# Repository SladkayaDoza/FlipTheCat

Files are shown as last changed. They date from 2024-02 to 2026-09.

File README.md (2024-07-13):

# FlipTheCat

Multitool for working with radio signals, based on FlipperZero on the basis of esp32 with less functionality and completely self-assembly. Use cc1101 module.
___
I really want to write programs in flipper zero, but I don't have the money for it.  
I would appreciate any support.
Metamask - 0x55aB63c8359f82a16f5B1eb500CaBc8DB605ACE0

## Functions
- copying of an unlimited number of static signals (can be set in firmware)
- change signal code, rename signal name, delete code
- copy raw signal (start recording when signal appears on air), display signal data quantity, rename signal, delete signal
- On-air frequency analyzer, sensitivity setting, frequency tabular value output, received signal frequency output
- Brute force of 12 bit signals for opening of cinder barriers
- Bluetooth BLE emulation Keyboard (gamepad)
- GPIO Frequency generator, set frequency and filling
- Setting the broadcasting frequency and the start num of the 12-bit signal brute force
- Game 2048

## ToDo
- https://trello.com/b/FfUWApZh/flip-esp32

## Open Project
You can suggest changes or additional features

## Materials:
- cc1101 module
- lithium battery
- esp32 (s, s3, an other.., flash: 4+mb)
- 10 smd buttons (2 for up gamepad buttons)
- tp4057 type c charger with protection
- step up dc-dc and linear voltage stabilizer | or step up, down corverter 3.3v
- gpio output pins x18 (4+10+4)
- power switch
- 8 resistors 10k(5 for buttons, 2 for boot pins esp32, 1 for buzzer transistor), 3 resistors 100k (1 for buttons, 2 for volltage censor), 1 resistor 600 Ohm (for led)
- oled display 1.3"
- yellow led for indicator
- 2 capacitor (10v 220uf, 10v, 220pf)
- Buzzer 3.3v
- Transistor for buzzer

## After assembling
Once created, you need to calibrate the buttons and the resistive divider to output the battery voltage
* To calibrate the buttons, uncomment line 11 in the "tick.ino" file
* To calibrate the voltage you need to change the coefficients in the Function mainn()
According to the formula - getVolltage() * 3.26 * ((r1 + r2) / r2) / 4096
When connecting to a computer via UART, do not connect 3.3v from the programmer, for correct display of values from the buttons

## © Copyright
* ✖ | Not Commercial Use

##	Example of a finished product:
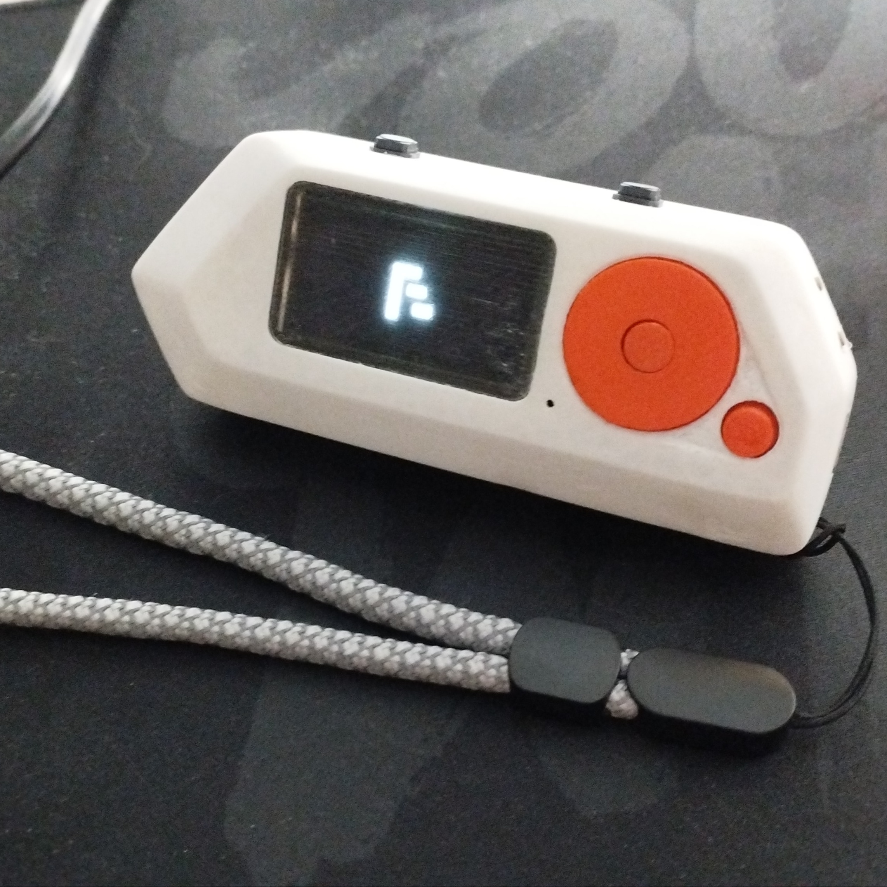
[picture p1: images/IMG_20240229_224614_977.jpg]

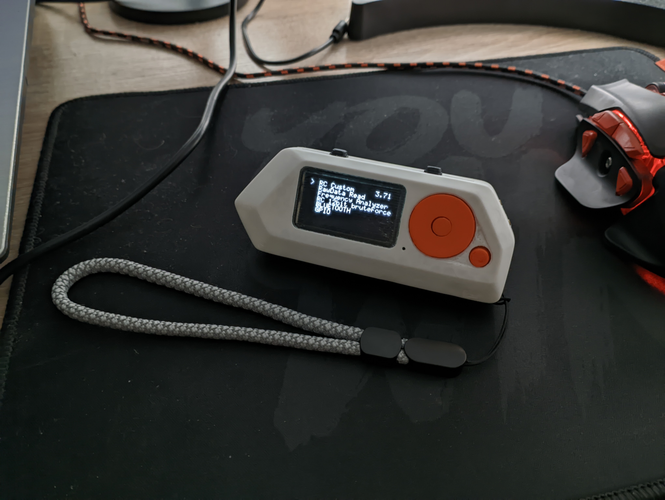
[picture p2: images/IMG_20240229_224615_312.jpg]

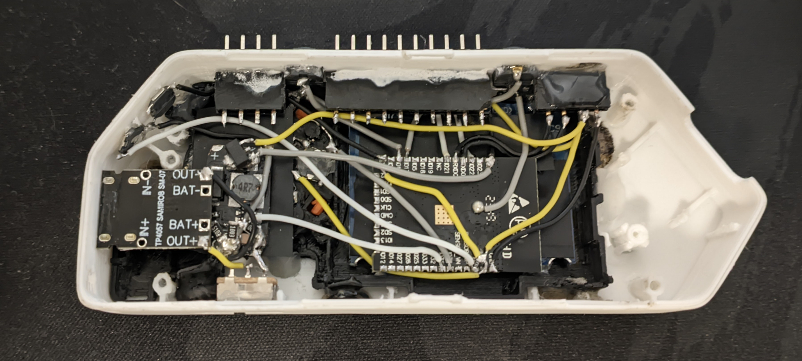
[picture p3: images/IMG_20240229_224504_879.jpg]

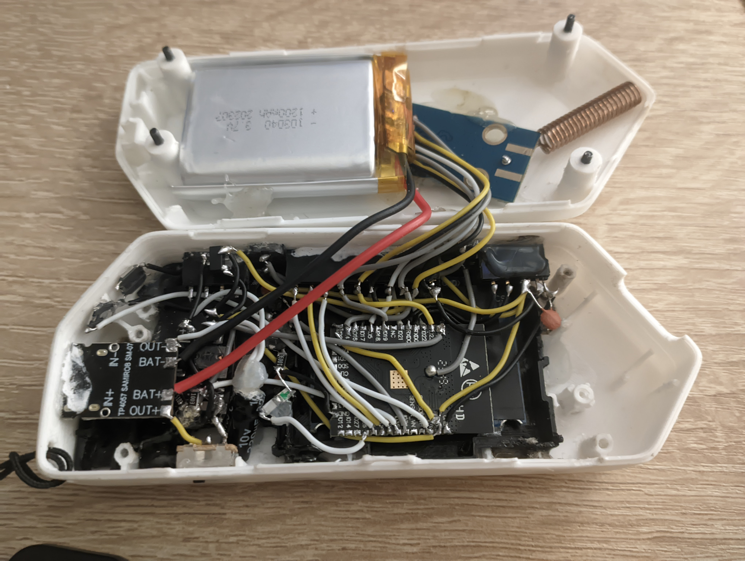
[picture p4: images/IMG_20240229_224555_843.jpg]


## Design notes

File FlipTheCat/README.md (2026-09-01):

# FlipTheCat

Многофункциональный инструмент для работы с сигналами на базе **ESP32**
(в духе Flipper Zero): суб-ГГц радио (CC1101), Bluetooth (BLE), управление GPIO,
анализатор частот и набор игр. Фреймворк — **Arduino**, сборка — **PlatformIO**.

> ⚠️ Инструмент предназначен для авторизованного тестирования, исследований и
> обучения на **собственном оборудовании**. Ответственность за использование
> несёт владелец устройства.

## Возможности

- **RC Custom** — запись и передача кодов RCSwitch (data + bits).
- **RawData Read** — запись/воспроизведение «сырых» суб-ГГц сигналов + просмотрщик.
- **Frequency Analyzer** — поиск пиковой частоты по RSSI.
- **RC 12bit bruteForce** — перебор 12-битных кодов.
- **Bluetooth** — BLE-клавиатура (мышь — задел).
- **WiFi** — пассивный анализ эфира: сканер точек доступа, монитор загруженности
  каналов, сниффер кадров (promiscuous), список станций в эфире. Только приём,
  без активных атак.
- **Temp** — ИК-термометр MLX90614 (модуль GY-906) по I2C: температура объекта и
  окружения в °C, калибровка‑смещение, пресеты эмиссивности по типу поверхности.
- **GPIO** — управление выходными пинами (ШИМ).
- **Settings** — частота, бипер, выбор CC-модуля (внутр./внешн.), полоса RxBW.
- **Games** — 2048, Cat, Space Impact.

## Быстрый старт

```bash
pio run                 # сборка
pio run -t upload       # прошивка ESP32 (esp32dev)
pio device monitor      # монитор порта, 115200
```

Отладочный вывод в Serial по умолчанию выключен — включается
`#define FTC_DEBUG_SERIAL` в `src/config/build_config.h`.

## Структура

```
src/
├── main.cpp        точка входа, экраны RC/Raw/Freq/Brute, таблицы меню
├── config/         pins.h (распиновка), build_config.h (флаги/версия)
├── core/           global_vars (состояние), menu (реестр модулей runMenu)
├── hal/            железо: display, button, tick, buzzer, adc, gpioPins, radio, fileSystem
├── ui/             pointer, tools (клавиатура/число/подтверждение), view, logo, nothing
├── apps/           GPIO, settings, bluetooth, wifi_app, temp, games
└── games/          game2048, gamecat, tiles, space impact (game_space_impact + si_*)
lib/                вендоренные библиотеки (точные версии — источник истины)
docs/               документация (см. ниже)
```

## Документация

| Документ | О чём |
|---|---|
| [docs/01_CURRENT_STRUCTURE.md](docs/01_CURRENT_STRUCTURE.md) | Структура «как было» (до реструктуризации) |
| [docs/02_ARCHITECTURE.md](docs/02_ARCHITECTURE.md) | Актуальная архитектура, слои, поток управления |
| [docs/03_ADDING_MODULES.md](docs/03_ADDING_MODULES.md) | Как добавить свой модуль (реестр меню) |
| [docs/04_IMPROVEMENTS.md](docs/04_IMPROVEMENTS.md) | Аудит: исправления, что не трогали и почему, идеи развития |

## Железо (кратко)

OLED SSH1106 128×64 (I²C 21/22), CC1101 (VSPI 18/19/23, CS 5/13, GDO0 4),
кнопки-джойстик на АЦП 34, доп. кнопки 0/16, LED 26, бипер 27, батарея 35,
выходы GPIO 32/33/25. Полная карта — в [`src/config/pins.h`](src/config/pins.h).

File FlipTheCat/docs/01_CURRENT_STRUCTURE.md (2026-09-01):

# FlipTheCat — структура проекта (состояние «как есть»)

> Этот документ описывает архитектуру проекта **до** реструктуризации.
> Новая архитектура описана в [`02_ARCHITECTURE.md`](02_ARCHITECTURE.md),
> список найденных проблем и исправлений — в [`04_IMPROVEMENTS.md`](04_IMPROVEMENTS.md).

## 1. Что это

**FlipTheCat** — многофункциональный инструмент для работы с радиосигналами
на базе **ESP32**, вдохновлённый Flipper Zero. Устройство собрано на фреймворке
**Arduino** и собирается через **PlatformIO**.

Основные возможности (пункты главного меню):

| # | Пункт меню | Файл реализации | Назначение |
|---|---|---|---|
| 0 | `RC Custom` | `main.cpp: rcLay()` | Запись/передача кодов RCSwitch (data + bits) |
| 1 | `RawData Read` | `main.cpp: rawLay()` | Запись/воспроизведение «сырых» radio-сигналов (тайминги) |
| 2 | `Frequency Analyzer` | `main.cpp: detectSignal()` | Поиск пиковой частоты по RSSI |
| 3 | `RC 12bit bruteForce` | `main.cpp: rc12bitBruteForce()` | Перебор 12-битных кодов |
| 4 | `BLUETOOTH` | `bluetooth.cpp` | BLE-клавиатура (мышь — заглушка) |
| 5 | `GPIO` | `GPIO.cpp: gpioLay()` | Управление 3 выходными пинами (ШИМ) |
| 6 | `Settings` | `settings.cpp: settings()` | Частота, бипер, CC-модуль, RxBW |
| 7 | `Games` | `games.cpp: games()` | 2048, Cat (сокобан), Space Impact |

## 2. Аппаратная часть и распиновка

| Периферия | Интерфейс / пины | Примечание |
|---|---|---|
| OLED-дисплей `SSH1106 128×64` | I²C (SDA=21, SCL=22), `Wire.setClock(800000)` | Библиотека GyverOLED |
| Радиомодуль `CC1101` | VSPI: SCK=18, MISO=19, MOSI=23, CS=5 (внутр.) / 13 (внешн.) | Драйвер SmartRC-CC1101 |
| CC1101 GDO0 / линия данных RC | `RCPin = GPIO4` | Приём/передача RCSwitch и raw |
| Кнопки-джойстик (резистивная лестница) | ADC на `GPIO34` | up/right/back/down/ok/left по порогам |
| Кнопка `top_left` | `GPIO0` (`INPUT_PULLUP`) | В комментарии указан альт. пин 17 |
| Кнопка `top_right` | `GPIO16` (`INPUT_PULLUP`) | |
| Светодиод | `GPIO26` | Индикация приёма/передачи |
| Бипер | `GPIO27`, LEDC-канал 1 | |
| Замер напряжения батареи | ADC на `GPIO35` | Делитель R1=50.61k, R2=76.4k |
| Пользовательские выходы GPIO | pin1=`GPIO32`, pin2=`GPIO33`, pin3=`GPIO25` | ШИМ на pin1 через LEDC-канал 0 |

### Пороги АЦП для кнопок (`tick.cpp`)

Все кнопки-джойстик считываются с одного вывода `GPIO34` по диапазонам:

```
up    : 0    < a < 1800
right : 1800 < a < 2060
back  : 2060 < a < 2360
down  : 2360 < a < 2850
ok    : 2850 < a < 3623
left  : 3623 < a < 4096
```

## 3. Сборка и зависимости

`platformio.ini`:

```ini
[env:esp32dev]
platform      = espressif32
board         = esp32dev
framework     = arduino
monitor_speed = 115200
upload_speed  = 921600
```

Внешние библиотеки (вендорятся в `lib/`, версии из baseline-сборки):

| Библиотека | Версия | Для чего |
|---|---|---|
| ArduinoJson | 7.0.3 | Хранение конфигов и сигналов в JSON |
| EncButton | 3.5.2 | `VirtButton` — виртуальные кнопки/дебаунс |
| ESP32 BLE Keyboard | 0.3.2 | BLE HID-клавиатура |
| GyverIO | 1.3.4 | Вспомогательный I/O |
| GyverOLED | 1.6.1 | Драйвер OLED |
| NimBLE-Arduino | 1.4.1 | BLE-стек |
| SmartRC-CC1101-Driver-Lib | 2.5.7 | Драйвер CC1101 |
| rc-switch | 2.6.4 | Кодирование/декодирование RC-протоколов |

Файловая система — **SPIFFS** (`SPIFFS.begin(true)` — форматирует при первом старте).

**Baseline-метрики сборки:** RAM 16.4% (53 880 B), Flash 56.6% (742 237 B).

## 4. Модель данных (SPIFFS + ArduinoJson)

В памяти живут три глобальных `JsonDocument` (объявлены в `main.cpp`), каждый
загружается из своего файла при старте и **целиком** переписывается при любом изменении:

| Документ | Файл | Корневой объект | Содержимое |
|---|---|---|---|
| `docConfigFile` | `/config.json` | `config` → `objectConfigFile` | `pik`, `pikHz`, `externalССModule` |
| `doc` | `/raw.json` | `sensorData` → `objectDoc` | Метаданные raw-сигналов по индексу-ключу |
| `docRC` | `/rc.json` | `data` → `objectRC` | RC-коды: `name`, `frequency`, `data`, `bytes` |

Ключами объектов служат **строки индексов** (`"0"`, `"1"`, …), формируемые через
`String(pointer)`. Сами отсчёты raw-сигнала хранятся в **отдельных файлах**
`/rawN.json` (поле `RAW` — массив знаковых длительностей в мкс), на которые
ссылается `objectDoc[i]["RawData"]`.

> ⚠️ Ключ `externalССModule` содержит **кириллические** символы «СС» (U+0421),
> а не латинские «CC». Это работает, но легко приводит к ошибкам при ручном
> редактировании.

## 5. Пофайловая карта `src/`

### Ядро и точка входа
- **`main.cpp`** (926 строк) — «монолит»: `setup()`, `loop()`, главное меню
  `mainn()`, а также все экраны RC/Raw/BruteForce/Frequency/Bluetooth и функции
  CC1101 (`setupRx/setupTx/func_trans/func_reciv/…`). Форвард-декларации и
  массивы пунктов меню (`main_lay[8]`, `blue_lay[8]`) заданы прямо здесь.
- **`global_vars.h` / `global_vars.cpp`** — глобальное состояние: указатели
  режимов, частоты, RSSI, флаги, `extern`-объявления JSON-документов. Часть
  `#define`-ов и `extern`-объявлений **продублирована** в обоих файлах.
- **`tick.cpp` / `tick.h`** — `tk()`: опрос всех кнопок из АЦП + авто-выключение
  бипера. Вызывается в каждой итерации всех UI-циклов.
- **`button.h`** — `extern VirtButton up/down/left/right/ok/back/top_left/top_right`.
- **`display.h`** — `extern GyverOLED<SSH1106_128x64> oled`.

### Радио
- **`radio.cpp` / `radio.h`** — `RecordSignal()` (запись raw), `tryRecordSignalToBuffer()`
  (низкоуровневый захват переходов), `sendSamples()` (воспроизведение).
- Функции CC1101 (`setupRx/setupTx/func_trans/func_custom_translate/func_reciv/
  detectSignal/rc12bitBruteForce`) — внутри `main.cpp`.

### Файловая система и просмотр
- **`fileSystem.cpp` / `fileSystem.h`** — `saveJsonToFile()`, `readJsonFromFile()`.
- **`view.cpp` / `view.h`** — `viewer()` и `drawSignal()`: визуализация raw-сигнала
  с масштабированием и прокруткой.

### Ввод/вывод и утилиты
- **`tools.cpp` / `tools.h`** — экранная клавиатура `setName()`, ввод числа
  `setNumber()`, подтверждение `confirmReWrite()`, `addElementToFront()`.
- **`pointer.cpp` / `pointer.h`** — отрисовка курсоров `>` / `<`.
- **`buzzer.cpp` / `buzzer.h`** — `setupBuzzer()`, `beep()` (LEDC-канал 1).
- **`adc.cpp` / `adc.h`** — `getVolltage()` (64 замера АЦП с усреднением).
- **`logo.cpp` / `logo.h`** — заставка.
- **`nothing.cpp` / `nothing.h`** — пустышка-заглушка для незанятых пунктов меню.

### GPIO
- **`GPIO.cpp` / `GPIO.h`** — экран управления пинами.
- **`gpioPins.h`** — класс `OUTPIN` **и создание трёх объектов** `pin1/pin2/pin3`
  прямо в заголовке (см. риски ODR в отчёте).

### Настройки и Bluetooth
- **`settings.cpp` / `settings.h`** — экран настроек + `settingsRawBW()`, который
  запускает **отдельную FreeRTOS-задачу** на ядре 1 для отрисовки водопада RxBW.
- **`bluetooth.cpp` / `bluetooth.h`** — `selectKeyboard()` (рабочая BLE-клавиатура),
  `selectMouse()` (закомментирована).

### Игры
- **`games.cpp` / `games.h`** — меню игр и запуск экземпляров.
- **`game2048.h`** — класс `Game2048` (вся логика в заголовке).
- **`gamecat.h`** — класс `GameCat` (сокобан, логика в заголовке).
- **`tiles.h`** — битмапы 8×8 для GameCat.
- **Space Impact** (порт): `game_space_impact.h` (класс-обёртка + рендер в OLED),
  `si_engine.h` (графика/выстрелы/враги/сцена/сейвы), `si_types.h` (типы),
  `si_data.h` (уровни/враги/шрифт), `si_game_objects.h` (спрайты). Функции и
  массивы объявлены `static` прямо в заголовках.

## 6. Поток управления

```
setup()
  ├─ adcAttachPin(34), Wire@800kHz, oled.init(), drawLogo()
  ├─ pinMode кнопок/LED, Serial, SPIFFS.begin(true)
  ├─ readJsonFromFile ×3  (/raw.json, /rc.json, /config.json)
  ├─ инициализация бипера (если pik)
  └─ CC1101: setSpiPin → Init → setMHZ → SetRx → goSleep
loop() → mainn()
  └─ while(1): tk(); отрисовка меню при displayUpdate;
       ok.click() → switch(pointer) → соответствующий экран
```

Каждый экран — это **свой блокирующий `while(1)`-цикл**, который:
1. вызывает `tk()` для опроса кнопок,
2. перерисовывает OLED только по флагу `displayUpdate`/`updDisplay`,
3. выходит по `back.click()`/`back.hold()`.

Обмена сообщениями/событий нет — навигация построена на вложенных вызовах
функций-экранов и локальных флагах перерисовки.

## 7. Как сейчас добавляется новый модуль

Чтобы добавить пункт в главное меню, сегодня нужно вручную:
1. добавить строку в массив `main_lay[8]` в `main.cpp`;
2. написать форвард-декларацию функции экрана в `main.cpp`;
3. добавить `case` в `switch(pointer)` внутри `mainn()`;
4. реализовать функцию экрана (обычно новый `.cpp` + `.h`);
5. подключить заголовок в список `#include` в `main.cpp`.

Это ручная связка в четырёх местах одного файла — главный источник хрупкости
и основной объект реструктуризации (см. [`03_ADDING_MODULES.md`](03_ADDING_MODULES.md)).

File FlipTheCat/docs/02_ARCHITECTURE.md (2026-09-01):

# FlipTheCat — архитектура (после реструктуризации)

> «Как было» описано в [`01_CURRENT_STRUCTURE.md`](01_CURRENT_STRUCTURE.md).
> Как добавить свой модуль — в [`03_ADDING_MODULES.md`](03_ADDING_MODULES.md).
> Список исправлений и идей — в [`04_IMPROVEMENTS.md`](04_IMPROVEMENTS.md).

## 1. Идея

Прошивка осталась «однопоточным конечным автоматом на блокирующих экранах»
(так проще всего для устройства с одним пользователем и одним экраном), но:

- код разложен по слоям (`config / core / hal / ui / apps / games`);
- верхнеуровневые меню теперь **данные, а не код** — таблица `MenuItem[]`;
- пины и константы собраны в один `config/`;
- заголовки защищены `#pragma once`, устранены дубли определений и ODR-ловушки;
- исправлены зависания, гонки, утечки и просадки производительности
  (полный список — в `04_IMPROVEMENTS.md`).

## 2. Дерево каталогов

```
src/
├── main.cpp                 // setup()/loop(), функции CC1101, экраны RC/Raw/Freq/Brute, таблицы меню
├── config/
│   ├── pins.h               // ЕДИНАЯ карта выводов (все #define пинов + LEDC/ADC)
│   └── build_config.h       // версия, флаги, макросы логирования FTC_LOG/FTC_LOGLN
├── core/
│   ├── global_vars.h/.cpp   // глобальное состояние (радио, бипер, настройки, JSON-документы)
│   └── menu.h/.cpp          // MenuItem + универсальный драйвер runMenu()  ← реестр модулей
├── hal/                     // абстракция железа
│   ├── display.h            // extern GyverOLED oled
│   ├── button.h             // extern VirtButton up/down/.../top_left/top_right
│   ├── tick.h/.cpp          // tk(): опрос кнопок с АЦП + авто-выключение бипера
│   ├── buzzer.h/.cpp        // бипер (LEDC ch1)
│   ├── adc.h/.cpp           // getVolltage(): напряжение батареи (с кешем)
│   ├── gpioPins.h/.cpp      // класс OUTPIN + объекты pin1/pin2/pin3 (LEDC ch2/3/4)
│   ├── radio.h/.cpp         // запись/воспроизведение raw-сигналов
│   └── fileSystem.h/.cpp    // save/readJsonToFile (SPIFFS, прямой стрим)
├── ui/                      // переиспользуемые элементы интерфейса
│   ├── pointer.h/.cpp       // курсоры > / <
│   ├── tools.h/.cpp         // setName() (клавиатура), setNumber(), confirmReWrite()
│   ├── view.h/.cpp          // viewer(): визуализация raw-сигнала
│   ├── logo.h/.cpp          // заставка
│   └── nothing.h/.cpp       // заглушка-пустышка
├── apps/                    // экраны-функции верхнего уровня
│   ├── GPIO.h/.cpp          // управление выходными пинами
│   ├── settings.h/.cpp      // настройки + экран RxBW
│   ├── bluetooth.h/.cpp     // BLE-клавиатура/мышь
│   ├── wifi_app.h/.cpp      // Wi-Fi: сканер / монитор каналов / сниффер / станции (только приём)
│   ├── temp.h/.cpp          // ИК-термометр MLX90614/GY-906 (I2C 0x5A)
│   └── games.h/.cpp         // подменю игр (таблица MenuItem)
└── games/                   // движки игр
    ├── game2048.h
    ├── gamecat.h
    ├── tiles.h
    ├── game_space_impact.h
    └── si_engine.h / si_types.h / si_data.h / si_game_objects.h
```

Все подпапки добавлены в путь поиска заголовков через `build_flags = -I ...`
в `platformio.ini`, поэтому прежний стиль `#include <foo.h>` работает без
изменений вне зависимости от того, в какой папке лежит файл.

## 3. Слои и зависимости

```
main.cpp ──▶ core (menu, global_vars) ──▶ hal ──▶ железо/драйверы
   │            ▲                           ▲
   └─▶ apps ────┘        ui ────────────────┘
              apps ─▶ ui, hal, core
              games ─▶ hal, ui, core
```

- **config** — не зависит ни от чего (только `#define`).
- **hal** — тонкая обёртка над железом и драйверами (CC1101, OLED, SPIFFS, LEDC).
- **core** — общее состояние (`global_vars`) и драйвер меню (`menu`).
- **ui** — ввод/вывод, не привязанный к конкретной функции (клавиатура, курсоры).
- **apps** — конкретные функции устройства; каждая экспортирует функцию-экран.
- **games** — самодостаточные игровые движки.

## 4. Модель выполнения

`loop() → mainn() → runMenu(mainMenu, …, allowBack=false)` — корневой цикл,
который никогда не выходит. Выбор пункта вызывает функцию-экран; та крутит свой
блокирующий `while(1)`, опрашивая кнопки через `tk()`, перерисовывая OLED только
по флагу, и возвращается по кнопке back.

```
loop()
 └─ mainn()
     └─ runMenu(mainMenu)                 // рисует таблицу, диспетчеризует
         ├─ rcLay()          (main.cpp)
         ├─ rawLay()         (main.cpp) ── rawMenu(), viewer()
         ├─ detectSignal()   (main.cpp)
         ├─ miBruteForce()   (main.cpp) ── rc12bitBruteForce()
         ├─ bluetoothLay()   (main.cpp) ── runMenu(bluetoothMenu) ── selectKeyboard()/selectMouse()
         ├─ wifiLay()        (apps/wifi_app.cpp) ── runMenu(wifiMenu) ── Scanner/Ch Monitor/Sniffer/Stations
         ├─ tempLay()        (apps/temp.cpp) ── MLX90614/GY-906 I2C-термометр
         ├─ gpioLay()        (apps/GPIO.cpp)
         ├─ settings()       (apps/settings.cpp) ── settingsRawBW()
         └─ games()          (apps/games.cpp)     ── runMenu(gamesMenu) ── 2048/Cat/Space Impact
```

## 5. Реестр модулей (`core/menu.h`)

```cpp
struct MenuItem {
  const char* name;   // подпись в меню
  void (*run)();       // функция-экран
};

void runMenu(const MenuItem* items, uint8_t count,
             bool showVoltage = false, bool allowBack = true);
```

`runMenu()` — единый драйвер списочного меню: рисует пункты, двигает курсор в
границах `count` (поэтому курсор не заезжает на пустые строки, как было раньше),
по OK вызывает `items[pointer].run()`, по back выходит (кроме корневого меню).

Три таблицы:
- `mainMenu[]` (`main.cpp`) — 8 функций устройства;
- `bluetoothMenu[]` (`main.cpp`) — Keyboard/Mouse;
- `gamesMenu[]` (`apps/games.cpp`) — 2048/Cat/Space Impact.

Списки RC и Raw (`rcLay`/`rawLay`) НЕ используют `runMenu`, потому что рисуют
динамические имена из JSON и поддерживают постраничную прокрутку — это отдельные
экраны, а не фиксированные таблицы.

## 6. Хранилище (SPIFFS + ArduinoJson v7)

Без изменений по смыслу (см. `01_CURRENT_STRUCTURE.md` §4), но:

- `saveJsonToFile()` теперь стримит прямо в файл, без промежуточной `String`;
- на старте контейнеры создаются надёжно: `.as<JsonObject>()`, а если пусто —
  `.to<JsonObject>()` (раньше на «чистом» устройстве все сохранения были no-op);
- ключ конфигурации переименован из кириллического `externalССModule` в
  ASCII `externalCCModule`.

> ⚠️ После обновления прошивки, если ранее была включена настройка «External CC
> module», её нужно один раз включить заново (старый кириллический ключ больше
> не читается). Значение по умолчанию — Internal.

## 7. Карта выводов

Полностью описана в [`config/pins.h`](../src/config/pins.h). Кратко:

| Назначение | Вывод |
|---|---|
| OLED I²C | SDA=21, SCL=22 |
| Кнопки-джойстик (АЦП) | 34 |
| top_left / top_right | 0 / 16 |
| LED / бипер | 26 / 27 (LEDC ch1) |
| Батарея (АЦП) | 35 |
| CC1101 | SCK18/MISO19/MOSI23, CS=5(внутр)/13(внешн), GDO0=4 |
| Выходы GPIO | 32/33/25 (LEDC ch2/3/4) |

## 8. Сборка

```bash
pio run                 # сборка
pio run -t upload       # прошивка
pio device monitor      # монитор порта (115200)
```

Отладочный вывод в Serial по умолчанию выключен. Чтобы включить — раскомментируйте
`#define FTC_DEBUG_SERIAL` в [`config/build_config.h`](../src/config/build_config.h).

> ⚠️ **Объём после добавления Wi-Fi.** Библиотека Wi-Fi тяжёлая: Flash вырос до
> ~87% раздела приложения (1.25 МБ), RAM до ~21.6%. Ещё помещается (~168 КБ
> запаса), но это основной потребитель flash. Если места перестанет хватать,
> нужна своя таблица разделов с бо́льшим app-разделом (без потери SPIFFS, где
> лежат `*.json`/`*.sav`).

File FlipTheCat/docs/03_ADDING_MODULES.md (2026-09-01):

# Как добавить свой модуль

Этот документ показывает, как расширять FlipTheCat. Благодаря реестру меню
(`core/menu.h`) добавление функции в главное меню — это **один файл и одна строка
в таблице**, а не правка switch/массивов/forward-деклараций в четырёх местах.

## Что такое «модуль»

Модуль — это функция-экран с сигнатурой:

```cpp
void myModule();
```

Она блокирующая: внутри крутится свой цикл `while (1)`, который:
1. вызывает `tk()` для опроса кнопок;
2. перерисовывает OLED только когда что-то изменилось (по флагу);
3. выходит (`return`/`break`) по кнопке **back**.

Управление возвращается в `runMenu()`, который перерисует меню.

## Шаг 1. Создать файл модуля

Положите новый экран в `src/apps/` (для функций устройства) или в подходящий слой.
Пример — `src/apps/hello.cpp`:

```cpp
#include <Arduino.h>
#include <display.h>   // oled
#include <button.h>    // up/down/ok/back/...
#include <tick.h>      // tk()
#include "hello.h"

void helloScreen() {
  bool redraw = true;
  while (1) {
    tk();                       // 1) опрос кнопок

    if (redraw) {               // 2) перерисовка по флагу
      redraw = false;
      oled.clear();
      oled.home();
      oled.setCursor(14, 0);
      oled.print("Hello, FlipTheCat!");
      oled.update();
    }

    if (back.click() || back.hold()) return;  // 3) выход по back
  }
}
```

И заголовок `src/apps/hello.h`:

```cpp
#pragma once
void helloScreen();
```

> Каталоги `src/apps`, `src/hal`, `src/ui`, `src/core`, `src/config`, `src/games`
> уже в пути поиска заголовков (см. `platformio.ini`), поэтому `#include "hello.h"`
> и `#include <display.h>` работают из любого места.

## Шаг 2. Зарегистрировать пункт в меню

Откройте `src/main.cpp`, подключите заголовок и добавьте строку в таблицу
`mainMenu[]`:

```cpp
#include <hello.h>            // рядом с другими include

static const MenuItem mainMenu[] = {
  {"RC Custom", rcLay},
  // ... существующие пункты ...
  {"Games", games},
  {"Hello", helloScreen},     // ← новая строка. Всё.
};
```

`mainMenuCount` вычисляется автоматически (`sizeof(...) / sizeof(...)`), границы
навигации подстроятся сами. Пересоберите: `pio run`.

## Шаблоны экранов

### Список с курсором (готовый драйвер)

Если у вас фиксированный набор подпунктов — не пишите цикл вручную, используйте
`runMenu()`:

```cpp
#include <menu.h>

static void optA() { /* ... */ }
static void optB() { /* ... */ }

static const MenuItem subMenu[] = {
  {"Option A", optA},
  {"Option B", optB},
};

void myModule() {
  runMenu(subMenu, sizeof(subMenu) / sizeof(subMenu[0]));  // back — выход
}
```

### Ввод имени / числа / подтверждения (готовые виджеты из `ui/tools.h`)

```cpp
#include <tools.h>

String name = setName("Enter name");           // экранная клавиатура
int freq    = setNumber("Frequency", 433);      // ввод числа
if (confirmReWrite()) { /* пользователь подтвердил */ }
```

## Работа с железом

| Нужно | Подключить | Использовать |
|---|---|---|
| Экран | `<display.h>` | `oled.clear()/print()/update()` |
| Кнопки | `<button.h>` + `<tick.h>` | `tk();` затем `up.click()`, `ok.hold()`, `left.step()`… |
| Курсор в меню | `<pointer.h>` | `printPointer(pos)` |
| Пины (номера) | `<pins.h>` | `LED_PIN`, `RC_PIN`, `GPIO_OUT_PIN_1`… |
| Радио CC1101 | `<global_vars.h>` + `<ELECHOUSE_CC1101_SRC_DRV.h>` | `setupRx()/setupTx()`, `ELECHOUSE_cc1101.*` |
| Хранилище | `<fileSystem.h>` | `readJsonFromFile()`, `saveJsonToFile()` |
| Бипер | `<buzzer.h>` | `beep()` |
| Батарея | `<adc.h>` | `getVolltage()` |
| Логи (debug) | `<build_config.h>` | `FTC_LOG(x)`, `FTC_LOGLN(x)` |

## Правила, чтобы не сломать устройство

1. **Всегда `#pragma once`** в каждом заголовке.
2. **Не определяйте объекты/переменные в заголовках.** В `.h` — только объявления
   (`extern`, прототипы, `class {}` без объектов). Определения — в `.cpp`.
   (Именно из-за нарушения этого правила `gpioPins.h` был ODR-миной.)
3. **В блокирующих циклах всегда есть выход по back** и вызов `tk()` каждую итерацию.
4. **Не считывайте АЦП/долгие операции в каждом кадре** — кешируйте (пример:
   `getVolltage()` пересчитывается раз в секунду).
5. **Не крутите бесконечный цикл без условия выхода/паузы** — иначе watchdog
   перезагрузит ESP32 (см. исправления в `04_IMPROVEMENTS.md`).
6. **Пины — только через `config/pins.h`.** Не вводите новые `#define` пинов в модулях.
7. **JSON:** для новых данных используйте отдельный `JsonDocument`/файл, а после
   загрузки проверяйте `isNull()` и при необходимости создавайте контейнер `.to<JsonObject>()`.
8. **LEDC-каналы:** бипер занимает канал 1 (таймер 0), выходные пины — каналы 2/3/4.
   Для новой ШИМ берите свободный канал на свободном таймере.

## Пример: добавить пункт в подменю Bluetooth или Games

То же самое, но правьте таблицу `bluetoothMenu[]` в `main.cpp` или `gamesMenu[]`
в `apps/games.cpp` — по одной строке `{"Название", функция}`.

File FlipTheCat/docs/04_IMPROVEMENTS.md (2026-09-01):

# Отчёт: аудит, исправления и идеи развития

Аудит охватил все подсистемы: ядро/поток управления, радио (RC/CC1101/raw),
файловую систему/JSON, периферию/настройки, классические игры и движок Space
Impact, а также структуру сборки. Найдено и подтверждено (перепроверкой по коду)
**77 замечаний**: 6 высоких, 35 средних, 36 низких. Ниже — что исправлено, что
осознанно НЕ трогалось и почему, и что стоит добавить.

Все изменения проверены сборкой PlatformIO. Итог по памяти:

| | RAM | Flash |
|--|-----|---|
| База (до) | 53 880 B | 742 237 B |
| После | 53 664 B | 738 717 B |

> ⚠️ Прошивка проверена только **компиляцией** — на реальном ESP32 её не запускали.
> Поведенческие исправления (радио-тайминги, BLE, игры) обязательно проверьте на
> железе. Откат: ветка `refactor-baseline-backup` указывает на исходное состояние.

---

## 1. Критические исправления (high)

| Проблема | Файл | Что сделано |
|---|---|---|
| Зависание перебора 12-бит при `iy ≤ 0` (0·10 == 0 < 1000 → вечный цикл → watchdog) | `main.cpp` | `iy` ограничен `[1,4095]`, оба цикла-отступа защищены `draw > 0` |
| На «чистом» устройстве все сохранения были no-op (`.add<JsonObject>()` + `.as<JsonObject>()` над массивом → null) | `main.cpp` | инициализация через `.to<JsonObject>()`, после загрузки — фолбэк `isNull() → .to<>()` (данные не затираются) |
| `RecordSignal`: локальная `lastRecordDuration` затеняла глобальную → условие по времени мёртвое, короткие сигналы (<64 переходов) не записывались никогда | `hal/radio.cpp` | убрано затенение, глобальная сбрасывается в начале записи |
| Space Impact: `malloc` без проверки на NULL → гарантированный крах при фрагментации кучи на 20 fps | `games/si_engine.h` | проверки NULL во всех `malloc` (выстрелы, враги, объекты, пейзаж); при нехватке памяти элемент просто не создаётся |
| `gpioPins.h`: объекты `pin1/pin2/pin3` определены в заголовке без guard → ODR-мина при подключении из второго `.cpp` | `hal/gpioPins.*` | `#pragma once`, объекты объявлены `extern`, определены в `gpioPins.cpp` |

## 2. Структура и сборка (устранение хрупкости)

- **`#pragma once`** добавлен во все ~19 заголовков, где его не было.
- **Единый `config/pins.h`** — вся распиновка в одном месте; убраны дубли `#define`
  пинов, которые были и в `global_vars.h`, и в `global_vars.cpp`.
- **Убран запутанный дубль** `pinsCount(4)` / `pinsCounts(3)` — остался один
  `pinsCounts = GPIO_OUT_PIN_COUNT`; исключён потенциальный выход за границу
  `OutPinModeG[]`.
- **Реестр модулей** `core/menu.h` + `runMenu()` — меню стали таблицами `MenuItem[]`;
  добавление пункта = одна строка (см. `03_ADDING_MODULES.md`). Заодно исчезли
  «пустые» строки-заглушки в меню Games/Bluetooth/Settings, на которые заезжал курсор.
- **Каталоги** `config/core/hal/ui/apps/games` + `-I`-пути в `platformio.ini`.
- **`platformio.ini`** почищен (без дублей `platform`/`framework` в env); версии
  библиотек фиксируются копиями в `lib/` — из `lib_deps` убран явный пин
  ArduinoJson, который приводил к скачиванию несовместимой 7.4.x.
- **Кириллический ключ** `externalССModule` → ASCII `externalCCModule`.
- **Дубли макросов** `SCREEN_WIDTH/HEIGHT/boardSize` убраны из игровых заголовков.
- Удалён мёртвый код: `editPinParametr`, `digitalRead(RCPin);` без результата,
  неиспользуемые объявления `draw()/changeDirection()/update()` в `Game2048`,
  неиспользуемый буфер `recordedSignal[4096]` (**−16 КБ DRAM**).

## 3. Зависания и гонки

- **`detectSignal()`** больше не рекурсивен (перезапуск по OK был `detectSignal();`
  внутри себя → рост стека). Теперь внешний цикл перезапуска.
- **`run()` в обеих играх** (2048, Cat) — перезапуск после Game Over был рекурсией
  `run()→run()`; заменён на итеративный внешний цикл.
- **Экран RxBW** (`settings.cpp`) — убрана вторая FreeRTOS-задача на ядре 1. Она
  давала сразу три бага: гонку за общими `tiles/updDisplay/RxBW_Raw` (мьютекс
  защищал только читателя), утечку семафора (создавался на каждый вход, не
  удалялся) и `vTaskDelete` в момент удержания мьютекса/записи в I2C. Отрисовка
  раз в секунду не требует второго ядра — теперь всё в одном цикле.
- **Перебор 12-бит**: защищён и первый цикл-прогресс (падал при `start12bitBruteForce == 0`).

## 4. Производительность

- **`getVolltage()`**: было 64 блокирующих `analogRead` + `Serial.println` на КАЖДУЮ
  перерисовку главного экрана. Теперь кеш с пересчётом раз в секунду, 16 отсчётов,
  без Serial.
- **`detectSignal()`**: список частот сканировался дважды подряд идентично —
  дубликат удалён (вдвое меньше операций setMHZ/getRssi по SPI).
- **`saveJsonToFile()`**: прямой стрим в файл вместо сериализации в растущую
  `String` (меньше фрагментации кучи); убран отладочный дамп всего JSON в Serial.
- **`viewer()`**: `JsonArray` больше не резолвится из документа на каждый кадр —
  используется уже полученный `arr`; удалена мёртвая `static` переменная.
- **Space Impact**: между кадрами добавлен `delay(1)` (отдаёт CPU, кормит watchdog).

## 5. Функциональные баги

- **CC1101/raw**: `uint16_t tmmm = millis()` (усечение) → `unsigned long`;
  `RecordSignal` возвращает статус, и `rawLay` не сохраняет частичную запись при
  прерывании по back; в `sendSamples` локальная `delay` (затеняла `delay()`)
  переименована, удалена неиспользуемая `time`.
- **GPIO**: пины 2 и 3 теперь реально переключаются (раньше вызывался только
  `change()` без `start()/off()`); OK на подстроках учитывает выбранную строку;
  подписи показывают реальные GPIO (32/33/25); каждый пин на своём LEDC-канале
  (2/3/4) — устранён конфликт таймера с бипером (канал 1).
- **2048**: старт с 2 тайлов (а не 4); новые тайлы 90% «2»/10% «4» (было всегда «4»
  из-за `random(1)`); тайл добавляется только если ход изменил поле.
- **GameCat**: `resetGame()` сбрасывает флаг `out`; поле `uint8_t` вместо `uint16_t`.
- **Space Impact**: `SI_GetEnemy` проверяет данные ДО выделения (не кэширует мусор);
  размер врага берётся по всем кадрам анимации (был по нулевому); устранено чтение
  освобождённой памяти в цикле столкновений; исправлен выход за границу `Start[-1]`
  в таблице рекордов; буфер `ScoreText` расширен до 12 (защита от битого сейва).
- **Ввод**: диапазоны АЦП кнопок стыкуются без зазоров (нижняя граница `>=`).
- **Диалоги**: курсор удаления RC (`deleteRC`) всегда открывается на «No»
  (был `static` — мог открыться на «Yes»); подменю `menuRc` открывается на первом пункте.
- **`view.cpp`**: защита от деления на ноль в `map()` при сильном зуме.
- **Настройки**: курсор ограничен реальными 5 строками (был общий ITEMS=8).

---

## 6. Что осознанно НЕ менялось (и почему)

| Замечание | Причина |
|---|---|
| Логика захвата `tryRecordSignalToBuffer` (подсчёт коротких <80 мкс переходов завышает `size`) | Микросекундный тайминг захвата RF; правка рискует сломать основную функцию, а проверить без железа нельзя. **Рекомендуемая правка** — увеличивать счётчик только при реальной записи отсчёта и ресинхронизировать `currentInput` на пропуске, сохранив ограничитель 4096. |
| Добавить `yield()` внутрь цикла захвата | **НЕЛЬЗЯ**: `yield()` посреди µs-точного захвата разрушит тайминг записи. Аудиторская рекомендация здесь неприменима. |
| Движок Space Impact как `static` в заголовках | Работает как единый TU (включается только из `games.cpp`). Полное разделение на `.cpp` — большой риск для рабочего порта без возможности прогонов. `#pragma once` уже стоит. |
| Методы классов игр определены в заголовках | То же: один TU, ODR-нарушения нет. |
| `PixelMap` 1 байт/пиксель (4032 Б) вместо битовой упаковки (~504 Б) | Экономия RAM в обмен на усложнение отрисовки; сейчас RAM не в дефиците (16%). |
| `renderToOled` перебирает все 4032 пикселя с div/mod | Оптимизация (dirty-box/x-y счётчики) не тестируема без железа; риск визуальных багов. |
| `btStart()` перед `BleKeyboard.begin()` | Жизненный цикл NimBLE тонкий; убирать без прогонов рискованно. |
| `readJsonFromFile` не возвращает ошибку | Смена контракта требует переработки вызывающих; отдельная задача. |
| Отсутствие цели в GameCat (счёт захардкожен) | Это геймдизайн, а не баг; вынесено в идеи ниже. Флаг `out` уже починен. |
| `selectMouse()` — заглушка | Функционал не реализован в исходнике; см. идеи. |
| `SI_ScData`/уровни без bounds-guard | Безопасно, пока число уровней == 6; добавить проверку при расширении. |

## 7. Отклонённые при перепроверке замечания (4)

- «Циклы меню без `yield` → watchdog»: `tk()` неблокирующий, реальной блокировки нет.
- «Строковые ключи JSON churn'ят кучу на каждый кадр»: для коротких `int`-ключей
  на этой платформе выделения кучи не происходит в горячем пути так, как описано.
- «`JsonDocument` не освобождает ёмкость на `remove()`»: не соответствует модели
  памяти ArduinoJson v7.
- «`SI_HandleScenery` освобождает голову вместо удаляемого узла»: сценарий не
  воспроизводится при фактическом порядке узлов.

---

## 8. Что стоит добавить (идеи развития)

### Функциональность
- **WiFi-подсистема — РЕАЛИЗОВАНО** (`apps/wifi_app.cpp`, пункт меню WIFI). Четыре
  пассивных режима (только приём): сканер точек доступа (SSID/BSSID/RSSI/канал/
  шифрование), монитор загруженности каналов 1–13, сниффер кадров в promiscuous-
  режиме (счётчики mgmt/beacon/data/ctrl по каналу) и список станций в эфире
  (MAC/RSSI устройств). Активные/наступательные режимы (deauth, beacon-флуд,
  evil-twin, инъекция) сознательно НЕ добавлены — это DoS/атаки на чужие сети.
  Побочный эффект: библиотека Wi-Fi подняла Flash до ~87% раздела приложения
  (см. `02_ARCHITECTURE.md` §8).
- **WiFi-ретранслятор (STA+SoftAP c NAT) — НЕВОЗМОЖЕН на текущем фреймворке.**
  В прекомпилированном arduino-esp32 2.0.17 (IDF 4.4) IP-форвардинг отключён
  (`CONFIG_LWIP_IP_FORWARD is not set`), а функции NAPT (`ip_napt_enable`)
  скомпилированы из `liblwip.a` — проверено `nm`, определённых символов нет,
  вызов не слинкуется. Чтобы сделать настоящий ретранслятор, нужна пересборка
  фреймворка со своим `sdkconfig` (`CONFIG_LWIP_IP_FORWARD=y`,
  `CONFIG_LWIP_IPV4_NAPT=y`) — это переход на сборку arduino-as-IDF-component
  (дольше и сложнее). Сам STA+SoftAP без маршрутизации возможен, но клиенты не
  получат доступ к вышестоящей сети — то есть это не ретранслятор.
- **ИК-приёмопередатчик** (частый модуль для таких устройств): запись/воспроизведение
  ИК-команд, база популярных протоколов.
- **Декодирование субгигагерцовых протоколов** (Princeton, CAME, NICE, Keeloq-анализ)
  с показом расшифровки в UI, а не только «data/bytes».
- **NFC/RFID** (125 кГц / 13.56 МГц) при добавлении соответствующего модуля.
- **Хранение на SD-карте** вместо/вместе со SPIFFS — под большие библиотеки raw-сигналов.

### Качество жизни
- Сохранять `FrequencyPointer` и `RxBW_Raw` в `config.json` (сейчас сбрасываются при
  перезагрузке).
- Индикатор заряда в процентах + порог низкого заряда с предупреждением.
- Прокручиваемые списки и иконки в меню; общий помощник для «список из N строк».
- Экран «About» с версией прошивки (`FTC_FIRMWARE_VERSION`).
- Цель/победа в GameCat (толкнуть ящик на целевую клетку) — тогда счёт и `delay`
  станут осмысленными.
- Реализовать или честно помечать «Not implemented» пункт BLE Mouse.

### Инженерия
- Нативная среда PlatformIO (`env:native`) для юнит-тестов чистой логики (2048,
  разбор сигналов) без железа.
- OTA-обновление прошивки по Wi-Fi.
- Прошивка образа SPIFFS с дефолтными `config.json` (папка `data/`), чтобы «чистое»
  устройство стартовало с валидными файлами.
- Разнести CC1101-функции (`setupRx/Tx/func_*`) из `main.cpp` в `hal/radio.cpp`,
  а экраны RC/Raw — в отдельный `apps/`-модуль (следующий шаг реструктуризации).

### Производительность
- Частичные обновления OLED вместо полной перерисовки кадра.
- Битовая упаковка `PixelMap` в Space Impact (−~3.5 КБ RAM).
- Оптимизация `renderToOled` (x/y-счётчики без div/mod, dirty-box).

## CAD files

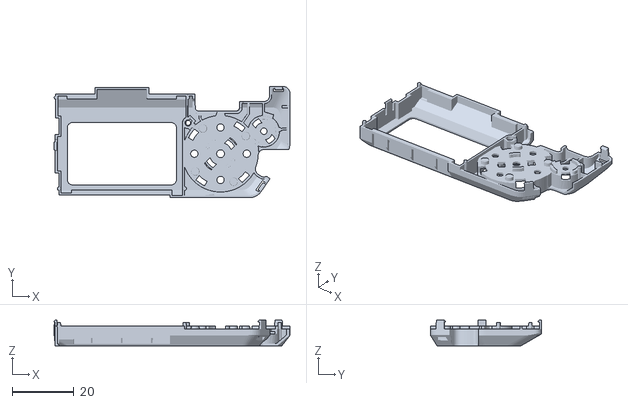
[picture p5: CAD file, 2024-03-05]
models/in flip.stl
76.5 x 36.1 x 8.30

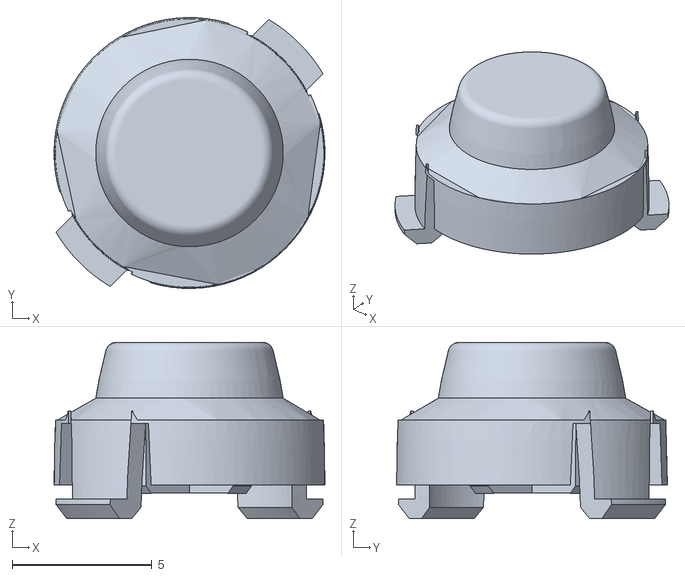
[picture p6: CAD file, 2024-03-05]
models/1 buttons long2.stl
9.69 x 9.69 x 6.30

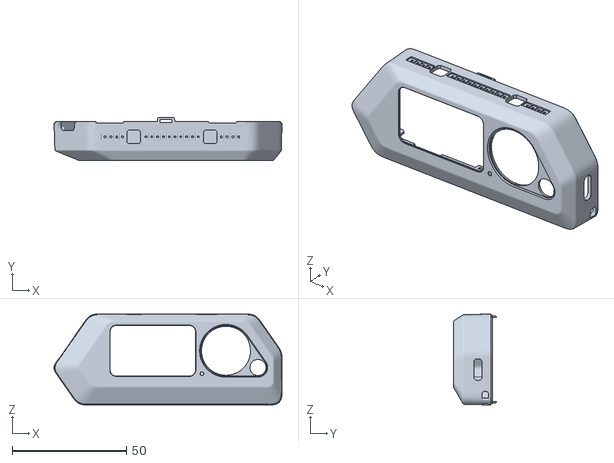
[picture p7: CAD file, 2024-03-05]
models/korp flip.stl
99.7 x 18.8 x 39.8

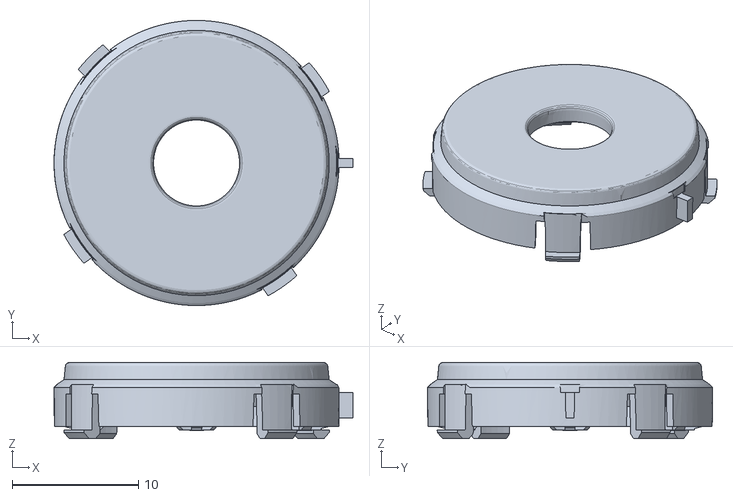
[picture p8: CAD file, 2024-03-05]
models/4 buttons long2.stl
23.7 x 22.6 x 6.05

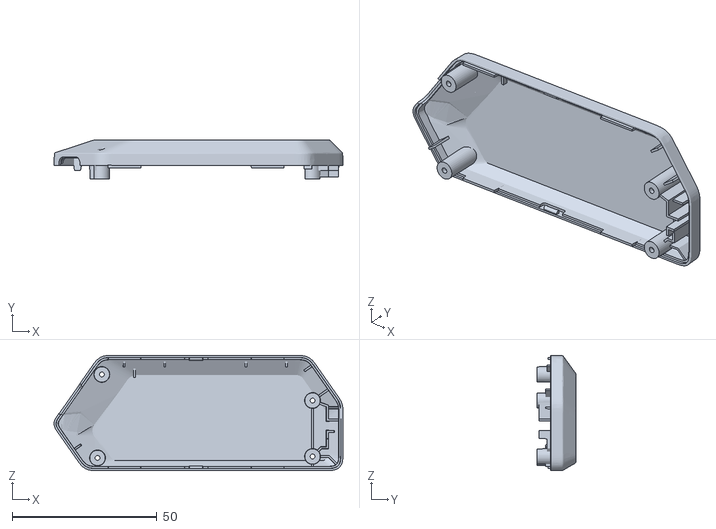
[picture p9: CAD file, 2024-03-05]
models/back cup flip.stl
99.7 x 13.4 x 39.8

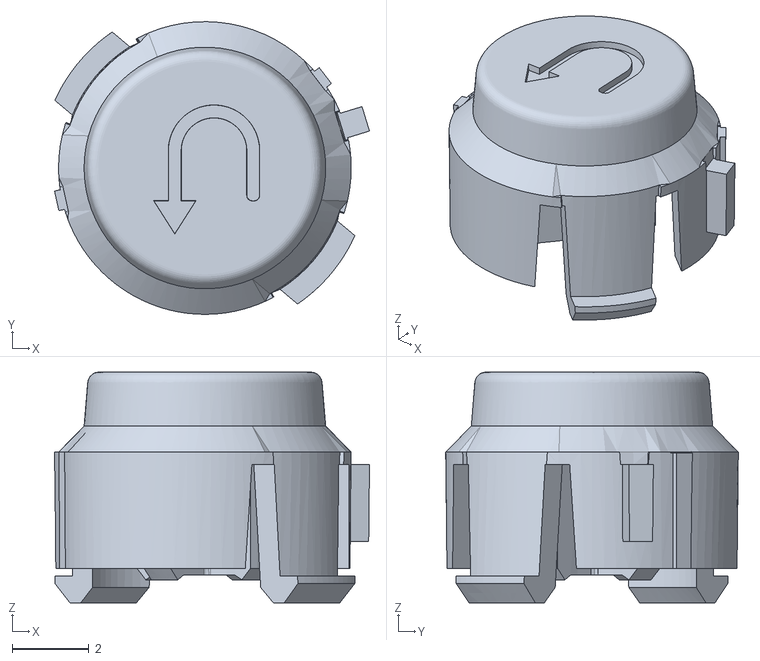
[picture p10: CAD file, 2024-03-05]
models/1 back buttons long.stl
8.19 x 7.61 x 6.00

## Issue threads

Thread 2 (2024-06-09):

button wiring

gg7200, 2024-06-09:
u didnt mension wiring for buttons

SladkayaDoza, 2024-06-09:
Hello, we're you from?
Yes, I didn't mention the wiring for the buttons, I had plans to make a
video about the creation.

вс, 9 июн. 2024 г., 10:34 gg7200 ***@***.***>:

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

SladkayaDoza, 2024-06-09:
Buttons are connected in series through 10 kOhm resistors and connected via a data line
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

gg7200, 2024-06-10:
hi im from India and thanks  your input really helped me out. By the way, I've been following your project, and I must say, it's quite impressive. Keep up the great work..

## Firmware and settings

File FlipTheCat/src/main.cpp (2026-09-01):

#include "NimBLEDevice.h"
#include <BleKeyboard.h>

#include <Arduino.h>

// #include <BleMouse.h>
// #define USE_NIMBLE

#include "SPIFFS.h"
#include "FS.h"
#include <ArduinoJson.h>

#include <GyverOLED.h>
GyverOLED<SSH1106_128x64> oled;

#include <Wire.h>
#include <EncButton.h>

VirtButton up;
VirtButton down;
VirtButton left;
VirtButton right;
VirtButton ok;
VirtButton back;
VirtButton top_left;
VirtButton top_right;

#include <global_vars.h>

#include <ELECHOUSE_CC1101_SRC_DRV.h>
#include <RCSwitch.h>
RCSwitch mySwitch = RCSwitch();



#include <logo.h>
#include <fileSystem.h>
#include <tick.h>
#include <buzzer.h>
#include <pointer.h>
#include <adc.h>
#include <GPIO.h>
#include <settings.h>
#include <tools.h>
#include <view.h>
#include <nothing.h>
#include <games.h>
#include <radio.h>
#include <bluetooth.h>
#include <wifi_app.h>
#include <temp.h>
#include <menu.h>





// typedef struct
// {
//   uint32_t frequency_coarse;
//   int rssi_coarse;
//   uint32_t frequency_fine;
//   int rssi_fine;
// } FrequencyRSSI;
// const int rssi_threshold = -70;



//  RAW DATA
JsonDocument docConfigFile;
JsonDocument doc;
JsonDocument docRC;
JsonObject objectConfigFile = docConfigFile["config"].to<JsonObject>();
JsonObject objectDoc = doc["sensorData"].to<JsonObject>();
JsonObject objectRC = docRC["data"].to<JsonObject>();



void mainn();
void rcLay();
void rawLay();
void detectSignal();
void rc12bitBruteForce();
void bluetoothLay();
void rawMenu(uint8_t pointer1);
void func_trans(uint8_t codek);
void menuRc(uint8_t pointer1);
void func_reciv(uint8_t cutr);
void reNameRC(int pointer);
void changeRC(int pointer);
void deleteRC(int pointer1);
void select_deleteRc(uint8_t pointer);


// Обёртка: rc12bitBruteForce не усыпляет радио сам — делаем это после (как в старом switch).
static void miBruteForce() {
  rc12bitBruteForce();
  ELECHOUSE_cc1101.goSleep();
}

// --- Таблицы меню (реестр модулей). Добавить пункт = дописать одну строку. ---
static const MenuItem mainMenu[] = {
  {"RC Custom", rcLay},
  {"RawData Read", rawLay},
  {"Frequency Analyzer", detectSignal},
  {"RC 12bit bruteForce", miBruteForce},
  {"BLUETOOTH", bluetoothLay},
  {"WIFI", wifiLay},
  {"Temp", tempLay},
  {"GPIO", gpioLay},
  {"Settings", settings},
  {"Games", games},
};
static const uint8_t mainMenuCount = sizeof(mainMenu) / sizeof(mainMenu[0]);

static const MenuItem bluetoothMenu[] = {
  {"Keyboard", selectKeyboard},
  {"Mouse", selectMouse},
};
static const uint8_t bluetoothMenuCount = sizeof(bluetoothMenu) / sizeof(bluetoothMenu[0]);


void setupRx() {
  ELECHOUSE_cc1101.Init();
  // ELECHOUSE_cc1101.setRxBW(812.50);
  // ELECHOUSE_cc1101.setRxBW(256);
  ELECHOUSE_cc1101.setMHZ(signalDetectionFrequencies[FrequencyPointer]);
  // if (!RxTxMode) {
  pinMode(RCPin, INPUT);
  mySwitch.disableTransmit();
  ELECHOUSE_cc1101.SetRx();
  mySwitch.enableReceive(RCPin);
  RxTxMode = !RxTxMode;
  // }
}
void setupTx() {
  ELECHOUSE_cc1101.Init();
  ELECHOUSE_cc1101.setMHZ(signalDetectionFrequencies[FrequencyPointer]);
  // if (RxTxMode) {
  pinMode(RCPin, OUTPUT);
  // mySwitch.disableReceive();  // trable
  ELECHOUSE_cc1101.SetTx();
  mySwitch.enableTransmit(RCPin);
  RxTxMode = !RxTxMode; 
  // }
}

#pragma region SETUP
void setup() {

  adcAttachPin(34);
  // analogSetCycles(16);
  // if (SPIFFS.exists("/raw.json")) {
  //   SPIFFS.remove("/raw.json");
  //   Serial.println("Файл удален");
  // } else {
  //   Serial.println("Файл не существует");
  // }
  Wire.setClock(800000L);

  oled.init();
  oled.clear();
  oled.setContrast(255);
  drawLogo();
  oled.update();

  for (int i = 0; i < pinsCounts; i++) {  // сброс режимов пользовательских GPIO
    OutPinModeG[i] = 0;
  }


  pinMode(top_left_pin, INPUT_PULLUP);
  pinMode(top_right_pin, INPUT_PULLUP);
  pinMode(led_pin, OUTPUT);

  digitalWrite(led_pin, LOW);

  Serial.begin(115200);

  if (!SPIFFS.begin(true)) {
    Serial.println("Ошибка инициализации SPIFFS");
  }

  readJsonFromFile("/raw.json", doc);
  readJsonFromFile("/rc.json", docRC);
  readJsonFromFile("/config.json", docConfigFile);
  Serial.println("ready");

  // Привязываем корневые объекты к загруженным документам. Если файл отсутствовал
  // или лежал в неверной форме (массив), .as<JsonObject>() вернёт null — тогда
  // создаём объект-контейнер через .to<JsonObject>(). Существующие данные при этом
  // не затираются (в отличие от безусловного .to<>()).
  objectDoc = doc["sensorData"].as<JsonObject>();  // frequency, name, RawData[]
  if (objectDoc.isNull()) objectDoc = doc["sensorData"].to<JsonObject>();
  objectRC = docRC["data"].as<JsonObject>();       // frequency, name, data, bytes
  if (objectRC.isNull()) objectRC = docRC["data"].to<JsonObject>();
  objectConfigFile = docConfigFile["config"].as<JsonObject>();  // pik, pikHz, externalCCModule
  if (objectConfigFile.isNull()) objectConfigFile = docConfigFile["config"].to<JsonObject>();

  // Buzzer
  pik = objectConfigFile["pik"].as<bool>();
  pikHz = objectConfigFile["pikHz"].as<int>();

  if (pik) setupBuzzer(pikHz);
  
  ELECHOUSE_cc1101.setSpiPin(18, 19, 23, (objectConfigFile["externalCCModule"].as<bool>() ? 13 : 5));
  ELECHOUSE_cc1101.Init();
  ELECHOUSE_cc1101.setMHZ(signalDetectionFrequencies[FrequencyPointer]);
  // ELECHOUSE_cc1101.setRxBW(58);
  mySwitch.enableReceive(RCPin);
  ELECHOUSE_cc1101.setGDO0(RCPin);
  // mySwitch.setPulseLength();
  ELECHOUSE_cc1101.SetRx();
  ELECHOUSE_cc1101.goSleep();
}

#pragma region LOOP
void loop() {
  mainn();
}

void mainn() {
  // Корневое меню, управляемое таблицей: не выходит по back, показывает напряжение.
  runMenu(mainMenu, mainMenuCount, /*showVoltage=*/true, /*allowBack=*/false);
}

#pragma region RC RAW LAY
void rawLay() {
  bool updDisplay = true;
  while (1) {
    static uint8_t pointer = 0;
    tk();
    if (updDisplay) {
      updDisplay = false;
      oled.clear();
      oled.home();
      for (int i = 0; i < 8; i++) {
        int ui = i + ((pointer / 8) * 8);
        oled.setCursor(14, i);
        String j = String(ui);
        if (objectDoc[j].as<JsonObject>().isNull()) {
          oled.print("__");
        } else {
          oled.print(objectDoc[j]["name"].as<const char*>());
        }
      }
      printPointer(pointer);
      oled.update();
    }

    if (ok.click() or ok.hold()) {
      String j = String(pointer);
      if (objectDoc[j]) {
        digitalWrite(led_pin, HIGH);

        oled.clear();
        oled.home();
        oled.print("Translation..");
        oled.update();

        JsonDocument rawSignal1;
        readJsonFromFile(objectDoc[j]["RawData"].as<const char*>(), rawSignal1); // Текст null
        sendSamples(rawSignal1["RAW"].as<JsonArray>());
        digitalWrite(led_pin, LOW);
        ELECHOUSE_cc1101.goSleep();
      }
      updDisplay = 1;
    }

    if (up.click() or up.step()) {
      pointer = constrain(pointer - 1, 0, RC_ITEMS - 1);
      updDisplay = 1;
    }
    if (down.click() or down.step()) {
      pointer = constrain(pointer + 1, 0, RC_ITEMS - 1);
      updDisplay = 1;
    }
    if (right.click() or right.hold()) {
      String j = String(pointer);
      JsonDocument rawSignal;
      JsonArray RawSignalArray = rawSignal["RAW"].to<JsonArray>();
      // Сохраняем запись только если она не была прервана кнопкой back —
      // иначе в /raw.json попадала бы частичная запись без size/name/frequency.
      if (RecordSignal(pointer, RawSignalArray, objectDoc)) {
        objectDoc[j]["RawData"] = "/raw" + j + ".json";
        saveJsonToFile("/raw.json", doc);
        saveJsonToFile(objectDoc[j]["RawData"].as<const char*>(), rawSignal);
      }

      ELECHOUSE_cc1101.goSleep();
      tk();
      updDisplay = 1;
    }
    if (back.click() or back.hold()) break;
    if (left.hold()) {
      rawMenu(pointer);
      updDisplay = 1;
    }
    if(top_left.click() or top_left.hold()) {
      settingsRawBW();
      updDisplay = 1;
    }
  }
}

#pragma region RC RAW MENU
void rawMenu(uint8_t pointer1) {
  String j = String(pointer1);
  bool updDisplay = true;
  tk();
  while (1) {
    static uint8_t pointer = 2;
    tk();
    if (updDisplay) {
      updDisplay = 0;
      oled.clear();
      oled.home();
      oled.setCursor(14, 0);
      oled.print("OBJ: ");
      if (objectDoc[j].as<JsonObject>().isNull()) {
        oled.print("[EMPTY]");
      } else {
        oled.print(objectDoc[j]["name"].as<const char*>());
      }
      oled.setCursor(14, 1);
      oled.print("size: ");
      oled.print(objectDoc[j]["size"].as<int>());
      oled.setCursor(14, 2);
      oled.print(" Rename");
      oled.setCursor(14, 3);
      oled.print(" Viewer");
      oled.setCursor(14, 4);
      oled.print(" Delete");

      printPointer(pointer);
      oled.update();
    }
    if (up.click() or up.step()) {
      pointer = constrain(pointer - 1, 2, 4);
      updDisplay = 1;
    }
    if (down.click() or down.step()) {
      pointer = constrain(pointer + 1, 2, 4);
      updDisplay = 1;
    }
    if (back.click() or back.hold()) break;
    if (ok.click() or ok.hold()) {
      switch (pointer) {
        case 2:
          objectDoc[j]["name"] = setName("Raw");
          break;
        case 3:
          viewer(j);
          break;
        case 4:
          if (SPIFFS.exists(objectDoc[j]["RawData"].as<const char*>())) {
            SPIFFS.remove(objectDoc[j]["RawData"].as<const char*>());
          }
          objectDoc.remove(j);
          saveJsonToFile("/raw.json", doc);
          return;
          break;
      }
      saveJsonToFile("/raw.json", doc);
      updDisplay = 1;
    }
  }
}

#pragma region RC LAY
void rcLay() {
  bool displayUpdate = 1;
  while (1) {
    static uint8_t pointer = 0;
    tk();
    if (displayUpdate != 0) {
      displayUpdate = 0;
      oled.clear();
      oled.home();
      for (uint8_t i = 0; i < 8; i++) {
        int ui = i + ((pointer / 8) * 8);
        oled.setCursor(14, i);
        // oled.print(trans_lay[ui]);
        String j = String(ui);
        if (objectRC[j].isNull()) {
          oled.print("__");
        } else {
          oled.print(objectRC[j]["name"].as<const char*>());
        }
      }
      printPointer(pointer);
      oled.update();
    }


    if (up.click() or up.step()) {
      pointer = constrain(pointer - 1, 0, RC_ITEMS - 1);
      displayUpdate = 1;
    }
    if (down.click() or down.step()) {
      pointer = constrain(pointer + 1, 0, RC_ITEMS - 1);
      displayUpdate = 1;
    }
    if (back.click() or back.hold()) break;
    if (ok.click() or ok.hold()) {
      func_trans(pointer);
      ELECHOUSE_cc1101.goSleep();
      displayUpdate = 1;
    }
    if (left.hold()) {
      menuRc(pointer);
      displayUpdate = 1;
    }
    if (right.click() or right.hold()) {
      String j = String(pointer);
      if (!objectRC[j].isNull()) {
        if (!confirmReWrite()) return;
      }
      func_reciv(pointer);
      ELECHOUSE_cc1101.goSleep();
      displayUpdate = 1;
    }
    delay(1);
  }
}

#pragma region DETECT SYGNAL
void detectSignal() {
  // Внешний цикл перезапуска заменяет прежнюю рекурсию detectSignal()->detectSignal(),
  // которая наращивала стек при каждом нажатии OK (риск переполнения стека).
  while (1) {
    setupRx();
    byte signalDetected = 0;
    bool changed = false;
    bool restart = false;
    detectedRssi = -100;
    detectedFrequency = 0.0;
    fineRssi = -100;
    fineFrequency = 0.0;
    oled.clear();
    oled.home();
    oled.print("Frequency Analyzer..");
    oled.setCursor(0, 1);
    oled.print("minRssi: ");
    oled.print(minRssi);
    oled.update();

    while (signalDetected <= 5) {
      tk();
      if (back.click()) return;
      if (ok.click()) { restart = true; break; }
      if (up.click() or up.step()) { minRssi++; changed = true; }
      if (down.click() or down.step()) { minRssi--; changed = true; }
      if (changed) {
        changed = false;
        oled.setCursor(0, 1);
        oled.print("minRssi: ");
        oled.print(minRssi);
        oled.update();
      }
      detectedRssi = -100;

      // Один проход по списку частот (раньше цикл был продублирован —
      // удвоенные setMHZ()/getRssi() без пользы).
      for (float fMhz : signalDetectionFrequencies) {
        ELECHOUSE_cc1101.setMHZ(fMhz);
        int rssi = ELECHOUSE_cc1101.getRssi();
        if (rssi >= detectedRssi) {
          detectedRssi = rssi;
          detectedFrequency = fMhz;
        }
      }

      if (detectedRssi >= minRssi) {
        for (float i = detectedFrequency - 0.3; i < detectedFrequency + 0.3; i += 0.02) {
          ELECHOUSE_cc1101.setMHZ(i);
          int rssi = ELECHOUSE_cc1101.getRssi();
          if (rssi >= fineRssi) {
            fineRssi = rssi;
            fineFrequency = i;
          }
        }

        signalDetected++;

        FTC_LOG("MHZ: "); FTC_LOG(detectedFrequency);
        FTC_LOG(" RSSI: "); FTC_LOGLN(detectedRssi);
        FTC_LOG("Fine MHZ: "); FTC_LOG(fineFrequency);
        FTC_LOG(" Fine RSSI: "); FTC_LOGLN(fineRssi);

        oled.setCursor(0, 1 + signalDetected);
        oled.print(detectedFrequency);
        oled.print(",");
        oled.print(detectedRssi);
        oled.print(" ");
        oled.print(fineFrequency);
        oled.print(",");
        oled.println(fineRssi);
        oled.update();
        delay(1);
      }
    }
    if (restart) continue;

    // Экран удержания результатов: OK — новый скан, Back — выход.
    while (1) {
      tk();
      if (back.click()) return;
      if (ok.click()) { restart = true; break; }
      if (up.click()) { minRssi++; changed = true; }
      if (down.click()) { minRssi--; changed = true; }
      if (changed) {
        changed = false;
        oled.setCursor(0, 1);
        oled.print("minRssi: ");
        oled.print(minRssi);
        oled.update();
      }
    }
    if (restart) continue;
    return;
  }
}

#pragma region BLUETOOTH
void bluetoothLay() {
  runMenu(bluetoothMenu, bluetoothMenuCount);
}




#pragma region RC MENU
void menuRc(uint8_t pointer1) {
  String j = String(pointer1);
  uint8_t pointer = 3;  // не static: подменю открывается на первом пункте
  bool updDisplay = true;
  while (1) {
    tk();

    if (updDisplay) {
      updDisplay = 0;
      oled.clear();
      oled.home();
      oled.setCursor(14, 0);
      oled.print("OBJ: ");
      if (objectRC[j].isNull()) {
        oled.print("[EMPTY]");
      } else {
        oled.print(objectRC[j]["name"].as<const char*>());
      }
      oled.setCursor(14, 1);
      oled.print("data: ");
      oled.print(objectRC[j]["data"].as<unsigned long>());

      oled.setCursor(14, 2);
      oled.print("bytes: ");
      oled.print(objectRC[j]["bytes"].as<unsigned int>());

      oled.setCursor(14, 3);
      oled.print(" Rename");

      oled.setCursor(14, 4);
      oled.print(" Edit");

      oled.setCursor(14, 5);
      oled.print(" Delete");

      printPointer(pointer);
      oled.update();
    }

    if (up.click() or up.step()) {
      pointer = constrain(pointer - 1, 3, 5);
      updDisplay = true;
    }
    if (down.click() or down.step()) {
      pointer = constrain(pointer + 1, 3, 5);
      updDisplay = true;
    }
    if (back.click() or back.hold()) break;
    if (ok.click() or ok.hold()) {
      switch (pointer) {
        case 3:
          reNameRC(pointer1);
          return;
          break;
        case 4:
          changeRC(pointer1);
          return;
          break;
        case 5:
          deleteRC(pointer1);
          return;
          break;
      }
    }
  }
}

#pragma region DELETE RC LAY
void deleteRC(int pointer1) {
  String j = String(pointer1);
  uint8_t pointer = 1;  // не static: диалог удаления всегда открывается на "No"
  bool updDisplay = 1;
  while (1) {
    tk();

    if (updDisplay) {
      updDisplay = 0;
      oled.clear();
      oled.home();
      oled.setCursor(28, 0);
      oled.print("Delete RC?");
      oled.setCursor(14, 1);
      oled.print("No");
      oled.setCursor(14, 2);
      oled.print("Yes");

      printPointer(pointer);
      oled.update();
    }

    if (ok.click() or ok.hold()) {
      switch (pointer) {
        case 1:
          return;
          break;
        case 2:
          select_deleteRc(pointer1);
          return;
          break;
      }
    }
    if(back.click()) return;

    if (up.click() or up.step()) {
      pointer = constrain(pointer - 1, 1, 2);
      updDisplay = true;
    }
    if (down.click() or down.step()) {
      pointer = constrain(pointer + 1, 1, 2);
      updDisplay = true;
    }
  }
}

#pragma region RENAME RC LAY
void reNameRC(int pointer) {
  String j = String(pointer);
  String mStr = setName("Raw");
  if (mStr.startsWith("tmp - ")) {
    return;
  }
  objectRC[j]["name"] = mStr;
  saveJsonToFile("/rc.json", docRC);
}

#pragma region MODIFY RC LAY
void changeRC(int pointer) {
  String j = String(pointer);
  objectRC[j]["data"] = setNumber("Change code", objectRC[j]["data"]);
  saveJsonToFile("/rc.json", docRC);

  // int data = setNumber("Change code", save_data.data_prog[pointer]);
  // save_data.data_prog[pointer] = data;
  // snprintf(trans_lay[pointer], colls, "%lu - %hu", save_data.data_prog[pointer], save_data.data_prog1[pointer]);
  // write_eeprom();
}


void select_deleteRc(uint8_t pointer) {
  String j = String(pointer);
  objectRC.remove(j);
  saveJsonToFile("/rc.json", docRC);
  // save_data.data_prog[pointer] = 0;
  // save_data.data_prog1[pointer] = 0;
  // trans_lay[pointer] = "__";
  // write_eeprom();
}

#pragma region TRANSMIT
void func_trans(uint8_t codek) {
  // String j = String(codek);
  char j[25];
  itoa(codek, j, 10);
  if (objectRC[j]["data"].isNull()) return;
  setupTx();
  digitalWrite(led_pin, HIGH);
  oled.clear();
  oled.setCursor(0, 0);
  oled.print("Transmition..");
  oled.update();
  // mySwitch.send(save_data.data_prog[codek], save_data.data_prog1[codek]);
  mySwitch.send(objectRC[j]["data"], objectRC[j]["bytes"]);
  // delay(400);
  digitalWrite(led_pin, LOW);
}


void func_custom_translate(unsigned long address, uint8_t byte) {
  setupTx();
  digitalWrite(led_pin, HIGH);
  oled.clear();
  oled.setCursor(0, 0);
  oled.print("Transmition..");
  oled.update();
  mySwitch.send(address, byte);
  // delay(700);
  digitalWrite(led_pin, LOW);
}

#pragma region RECEIVE
void func_reciv(uint8_t cutr) {
  setupRx();
  tk();
  int uo = 1;
  oled.clear();
  oled.home();
  oled.print("Reading..");
  // oled.print(ELECHOUSE_cc1101.getMode());
  oled.update();
  digitalWrite(led_pin, HIGH);
  while (uo == 1) {
    tk();
    if (back.click() or back.hold()) {
      digitalWrite(led_pin, LOW);
      return;
    }
    if (mySwitch.available()) {
      store1 = mySwitch.getReceivedValue();
      bitR1 = mySwitch.getReceivedBitlength();
      protoc = mySwitch.getReceivedProtocol();
      Serial.print("Received ");
      Serial.print(store1);
      Serial.print(" / ");
      Serial.print(bitR1);
      Serial.print("bit ");
      Serial.print("Protocol: ");
      Serial.println(protoc);

      mySwitch.resetAvailable();
      uo = 0;
      digitalWrite(led_pin, LOW);
    }
  }
  String j = String(cutr);
  char def[20];
  snprintf(def, 20, "%lu - %hu", store1, bitR1);
  String mStr = setName("Signal");  // <----
  if (mStr.startsWith("tmp - ")) {
    mStr = def;
  }
  objectRC[j]["name"] = mStr;
  objectRC[j]["frequency"] = FrequencyPointer;
  objectRC[j]["data"] = store1;
  objectRC[j]["bytes"] = bitR1;

  saveJsonToFile("/rc.json", docRC);
}

#pragma region BRUTE FORCE
void rc12bitBruteForce() {
  setupTx();
  // mySwitch.setPulseLength(250);
  oled.clear();
  oled.home();
  oled.print("Rc 12bit brute force");
  // oled.setCursor(0, 4);
  // oled.print("        0/4096      ");
  oled.update();

  uint8_t byt = 12;
  // Начальный код перебора кодов ограничиваем диапазоном [1, 4095]: значение 0
  // раньше зацикливало формирователь отступов (0*10 == 0 < 1000 всегда истинно).
  int iy = constrain(start12bitBruteForce, 1, 4095);
  for (int i = iy; i < 4096; i++) {
    tk();
    if (back.click() or back.hold()) return;
    if (ok.click() or ok.hold()) break;
    mySwitch.send(i, byt);
    iy = i;
    oled.setCursor(0, 4);
    oled.print("     ");
    for (long draw = i; draw > 0 && draw < 1000; draw *= 10) oled.print(" ");
    oled.print(i);
    oled.print("/4096      ");
    oled.update();
  }

  bool upd = 1;  // не static: не переносим состояние между входами в экран
  while (1) {
    tk();
    if (back.click() or back.hold()) return;
    if (ok.click() or ok.hold()) {
      func_custom_translate(iy, byt);
      ELECHOUSE_cc1101.goSleep();
      upd = 1;
    }
    // iy жёстко ограничен [1, 4095] — иначе отрицательное/нулевое значение
    // вызывало вечный цикл отрисовки и срабатывание watchdog.
    if (up.click())   { iy = constrain(iy + 1, 1, 4095); upd = 1; }
    if (down.click()) { iy = constrain(iy - 1, 1, 4095); upd = 1; }
    if (upd) {
      upd = 0;
      oled.setCursor(0, 4);
      oled.print("     ");
      for (long draw = iy; draw > 0 && draw < 1000; draw *= 10) oled.print(" ");
      oled.print(iy);
      oled.print("/4096      ");
      oled.update();
    }
  }
}

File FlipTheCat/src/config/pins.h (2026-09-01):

#pragma once
// =============================================================================
//  FlipTheCat — единая карта выводов (pin map)
//  Единственный источник истины для всех GPIO. Не дублируйте #define пинов
//  по другим файлам — подключайте этот заголовок.
// =============================================================================

// --- OLED (I2C, аппаратный Wire; выводы заданы платой ESP32 по умолчанию) ---
#define OLED_SDA_PIN 21
#define OLED_SCL_PIN 22
#define OLED_I2C_CLOCK 800000L

// --- Кнопки-джойстик (резистивная лестница на одном АЦП) ---
#define BUTTONS_ADC_PIN 34

// --- Дополнительные тактовые кнопки ---
#define TOP_LEFT_PIN 0   // альт. вариант разводки — 17
#define TOP_RIGHT_PIN 16

// --- Индикация / звук ---
#define LED_PIN 26
#define BUZZER_PIN 27

// --- Питание ---
#define BATTERY_ADC_PIN 35

// --- CC1101 (VSPI) ---
#define CC1101_SCK_PIN 18
#define CC1101_MISO_PIN 19
#define CC1101_MOSI_PIN 23
#define CC1101_CS_INTERNAL_PIN 5
#define CC1101_CS_EXTERNAL_PIN 13
#define RC_PIN 4  // CC1101 GDO0 / линия данных RCSwitch и raw

// --- Пользовательские выходы GPIO (управляются экраном GPIO) ---
#define GPIO_OUT_PIN_1 32
#define GPIO_OUT_PIN_2 33
#define GPIO_OUT_PIN_3 25
#define GPIO_OUT_PIN_COUNT 3

// -----------------------------------------------------------------------------
//  Совместимость со старыми именами (используются по всему коду).
//  Оставлены как алиасы, чтобы не переписывать каждый вызов сразу.
// -----------------------------------------------------------------------------
#define top_left_pin TOP_LEFT_PIN
#define top_right_pin TOP_RIGHT_PIN
#define led_pin LED_PIN
#define RCPin RC_PIN

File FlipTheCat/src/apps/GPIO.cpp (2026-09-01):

#include <Arduino.h>
#include <display.h>
#include <button.h>
#include <tick.h>
#include <nothing.h>
#include <pointer.h>
#include <global_vars.h>
#include <gpioPins.h>
#include <tools.h>

int pinsG[] = { GPIO_OUT_PIN_1, GPIO_OUT_PIN_2, GPIO_OUT_PIN_3 };  // реальные номера GPIO (32/33/25)
byte updOled = 0;

void oledUpdater(uint8_t pointer);
void changePin(uint8_t pointer1);
void printOutputPinsModeGPIO(int pointer);
void printOutputPinsFillingGPIO();
void printOutputPinsFrequencyGPIO();

const char* GPIOPinsMode[7] = {
  "mode: ",
  "frequency: ",
  "Filling: ",
  "",
  "",
  "",
  "",
};


void gpioLay() {
  static uint8_t pointer = 0;
  tk();
  oledUpdater(pointer);

  while (1) {
    tk();
    if (updOled == 1) {
      updOled = 0;
      oledUpdater(pointer);
    }

    if (right.click()) {
      pointer = constrain(pointer + 1, 0, pinsCounts);
      updOled = 1;
    }
    if (left.click()) {
      pointer = constrain(pointer - 1, 0, pinsCounts);
      updOled = 1;
    }
    if (back.click() or back.hold()) break;
    if (ok.click() && pointer != 0) {
      changePin(pointer);
      updOled = 1;
    }
  }
}

void changePin(uint8_t pointer1) {
  static uint8_t pointer = 1;
  tk();
  int redraw = 1;  // локальный флаг перерисовки (раньше назывался updOled и затенял файловый глобал)
  while (1) {
    tk();

    if (redraw == 1) {
      redraw = 0;
      oled.clear();
      oled.setCursor(0, 0);
      oled.print("Editing pin: ");
      oled.print(pinsG[pointer1 - 1]);
      for (int i = 1; i < 8; i++) {
        oled.setCursor(0, i);
        oled.print(GPIOPinsMode[i - 1]);
        switch (i - 1) {
          case 0: printOutputPinsModeGPIO(pointer1 - 1); break;
          case 1: printOutputPinsFrequencyGPIO(); break;
          case 2: printOutputPinsFillingGPIO(); break;
          case 3: nothing(); break;
          case 4: nothing(); break;
          case 5: nothing(); break;
          case 6: nothing(); break;
        }
      }
      printRightPointer(pointer);
      oled.update();
    }

    if (back.click() or back.hold()) break;
    // Курсор ограничен реальным числом строк-параметров (mode/frequency/filling).
    if (up.click() or up.hold()) {
      pointer = constrain(pointer - 1, 1, 3);
      redraw = 1;
    }
    if (down.click() or down.hold()) {
      pointer = constrain(pointer + 1, 1, 3);
      redraw = 1;
    }
    if (ok.click() or ok.hold()) {
      switch (pointer1 - 1) {
        case 0:
          switch (pointer - 1) {
            case 0:
              pin1.change();
              if (pin1.getState()) {
                pin1.start();
              } else {
                pin1.off();
              }
              OutPinModeG[pointer1 - 1] = !OutPinModeG[pointer1 - 1];
              break;
            case 1:
              pin1.setFrequency(setNumber("frequency", pin1.getFrequency()));
              break;
            case 2:
              pin1.setFilling(setNumber("filling", pin1.getFilling()));
              break;
          }
          break;
        case 1:  // pin2 — только режим LOW/HIGH (строка "mode")
          if (pointer - 1 == 0) {
            pin2.change();
            if (pin2.getState()) pin2.start(); else pin2.off();  // раньше hardware не трогали
            OutPinModeG[pointer1 - 1] = !OutPinModeG[pointer1 - 1];
          }
          break;
        case 2:  // pin3 — только режим LOW/HIGH
          if (pointer - 1 == 0) {
            pin3.change();
            if (pin3.getState()) pin3.start(); else pin3.off();
            OutPinModeG[pointer1 - 1] = !OutPinModeG[pointer1 - 1];
          }
          break;
      }
      redraw = 1;
    }
  }
}

void printOutputPinsModeGPIO(int pointer) {
  if (OutPinModeG[pointer] == 0) {
    oled.print("LOW");
  } else {
    oled.print("HIGH");
  }
}
void printOutputPinsFillingGPIO() {
  oled.print(pin1.getFilling());
}
void printOutputPinsFrequencyGPIO() {
  oled.print(pin1.getFrequency());
}

void oledUpdater(uint8_t pointer) {
  tk();
  oled.clear();
  if (pointer == 0) {
    oled.setCursor(0, 0);
    oled.print("Available pins: ");
    oled.setCursor(14, 1);
    for (int i = 0; i < pinsCounts; i++) {
      oled.print(pinsG[i]);
      if (i != pinsCounts - 1) {
        oled.print(" ");
      }
    }
    oled.print(";");

  } else {
    int pinSelect = pointer - 1;
    oled.setCursor(0, 0);
    oled.print("Selected pin: ");
    oled.print(pinsG[pinSelect]);
    for (int i = 1; i < 8; i++) {
      oled.setCursor(0, i);
      oled.print(GPIOPinsMode[i - 1]);
      switch (i - 1) {
        case 0: printOutputPinsModeGPIO(pointer - 1); break;
        case 1: if (pinSelect == 0) printOutputPinsFrequencyGPIO(); break;
        case 2: if (pinSelect == 0) printOutputPinsFillingGPIO(); break;
        case 3: nothing(); break;
        case 4: nothing(); break;
        case 5: nothing(); break;
        case 6: nothing(); break;
      }
    }
  }
  oled.update();
}

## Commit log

2024-03-05 3d models
    [1 back buttons long.stl, 1 buttons long2.stl, 4 buttons long2.stl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]
2024-03-12 Fix zero SetNumber, PWM pin
2024-03-22 deleteRC back button
2024-04-11 button config
2024-04-29 Advanced keyboard Set name
    телепортация курсора, ввод больших букв при удержании, быстрое перелистывание при удержании и изменение буквенного и спец символьного меню при выходе вверх и вниз курсором
2024-06-02 fix timer start
2024-06-14 if to switch settings panel
2024-07-08 ADC+Sensor panel
2024-10-23 ArduinoIDE to PlatformIO
2026-09-01 restructuring
    Полная реструктуризация проекта, перепись кода для лучше поддержки, описания работы проекта
